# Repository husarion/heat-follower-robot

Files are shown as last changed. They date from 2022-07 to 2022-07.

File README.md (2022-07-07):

# Heat Follower

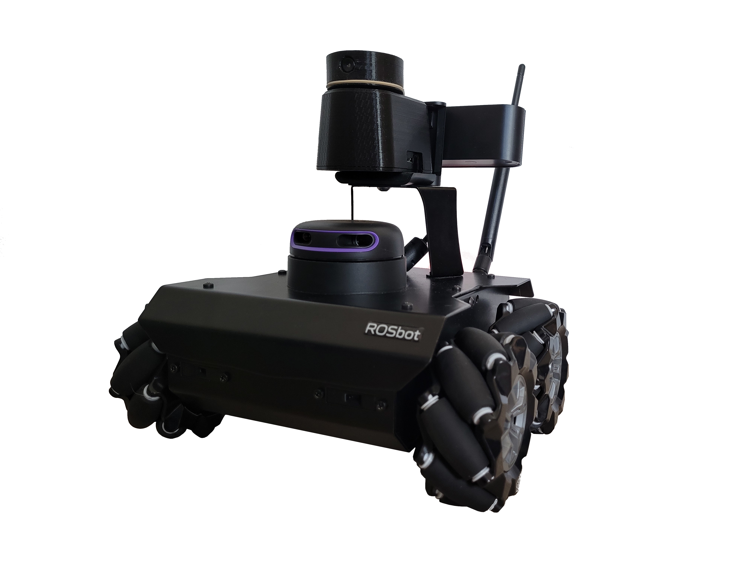
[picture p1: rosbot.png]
3d model


## Description

**Heat Follower** is a project based on the ROSbot Pro platform, that follows heat by using a 360 degree thermal camera. It utilizes a MLX90641 sensor which is a 16x12 pixels IR sensor array. With some custom hardware it is possible to rotate this sensor and get a surround infrared image.

## Hardware

Hardware used in this project:
 - [ROSbot PRO](https://husarion.com/manuals/rosbot/#rosbot-pro)
 - [IR Thermal Sensor Array](https://www.melexis.com/en/product/mlx90641/high-operating-temperature-fir-thermal-sensor-array)
 - [Slip Ring](https://www.sparkfun.com/products/13064)
 - [Custom PCB designed in Eagle](https://github.com/husarion/heat-follower-robot/tree/main/CAD/PCB)
 - [Custom enclosure designed in Fusion 360](https://github.com/husarion/heat-follower-robot/tree/main/CAD)
 
## Software

### Thermal Camera

Software for Thermal Camera is written in [PlatformIO](https://platformio.org/) IDE to ensure compatibility with multiple platforms. MLX90641 [API](https://github.com/melexis/mlx90641-library) is used to ensure proper communication with the IR Sensor. It is slightly modified to support STM32's hardware.
Micro-ROS libraries are mandatory to communicate with ROSbot.

### ROS2 Python Node

A simple Python node was written to process the input thermal image with OpenCV and steer the robot. 
When a heat source is detected, this node sends rotational and linear velocities via `/cmd_vel` topic. 

### ROS Description

 Topic | Node Name | Description 
 --- | --- | ---
 `/thermal_image` | `/thermal_camera` | Raw thermal image represented with grayscale image (temperature = pixel intensity/100). 
 `/tc_image_devel` | `/thermal_subscriber`| Normalized image with target object contours. 
 `/tc_goal_angle` | `/thermal_subscriber`| Arrow marker pointing at the target angle relative to the robot. 
 
Additionally there are 3 parameters

 Parameter | Node Name | Type | Description
 ---  | --- | --- | ---
 `target_min_temp` | `/thermal_subscriber` | int | Minimum temperature of object 
 `target_max_temp` | `/thermal_subscriber` | int | Maximum temperature of object
 `go_to_hottest_piont` | `/thermal_subscriber` | bool | If true, robot follows the hottest object. If false, robot follows object which temperature is within `target_min_temp` and `target_max_temp`.
 
System schematic diagram:

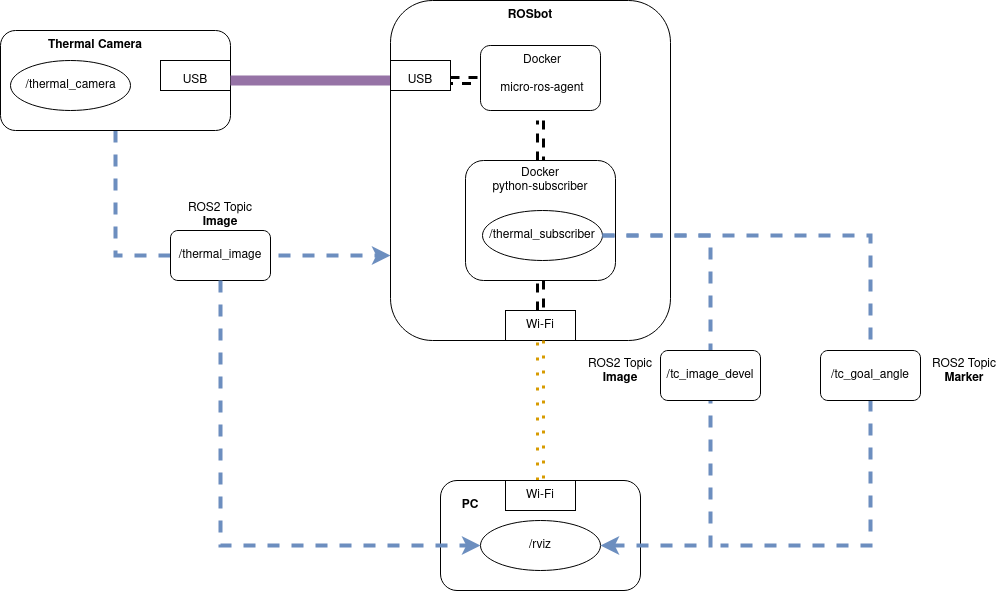
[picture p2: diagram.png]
diagram

 
The camera sends the main topic `/thermal_image` - a raw unprocessed image which is then transformed by `/thermal_subscriber` node. The transformed image published on `/tc_image_devel` containes a normalized image with a contour of an object selected by the algorithm. The angle of a selected object can also be visualized with `/tc_goal_angle` marker that publishes an arrow pointing from **base_link** to the direction of the object.

## Building the project

### Flashing MCU

Open the project with [Visual Studio Code](https://code.visualstudio.com/) with [PlatformIO](https://platformio.org/install/ide?install=vscode) plugin.

**This project is optimized for STM32F4 MCU's - keep that in mind when flashing on your hardware!**

After installing the **PlatformIO** extension to your VSCode, click its icon on the **Activity Bar** then from **Project Tasks** select **General** and **Upload**.

### Running on ROSbot

Clone **robot** folder to your ROSbot, connect the Thermal Camera via USB and run
```bash
cd robot/
docker-compose -f docker-compose.yaml up
```
After downloading all the necessary docker images ROSbot should follow warm objects nearby.

Due to issues connected with micro-ros agent, user must **unplug and plug** the Thermal Camera to reset the connection before running the docker compose. 
### Running Rviz on PC

Clone **pc** folder to your PC and run:

```bash
cd pc/
xhost local:root
docker-compose -f compose.pc.yaml up
```

Rviz should now pop up showing ROSbots surroundings in deep infrared.

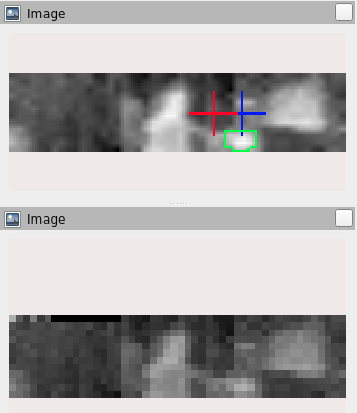
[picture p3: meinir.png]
rviz


If images are not visible click **Add** -> **By topic** -> **/thermal_image**

Here's ROSbot facing a kettle:

rb kettle

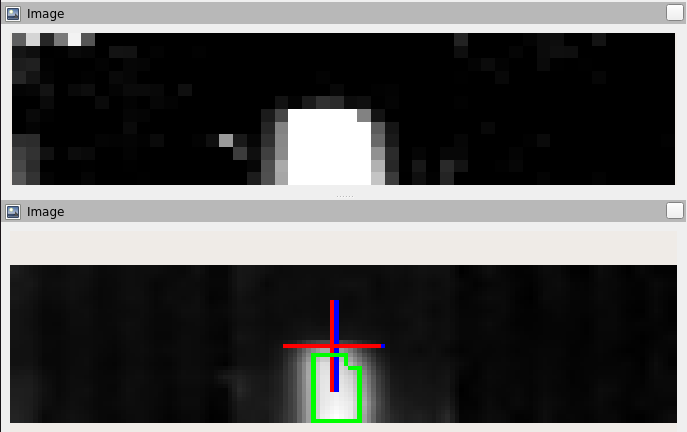
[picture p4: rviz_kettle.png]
rviz kettle


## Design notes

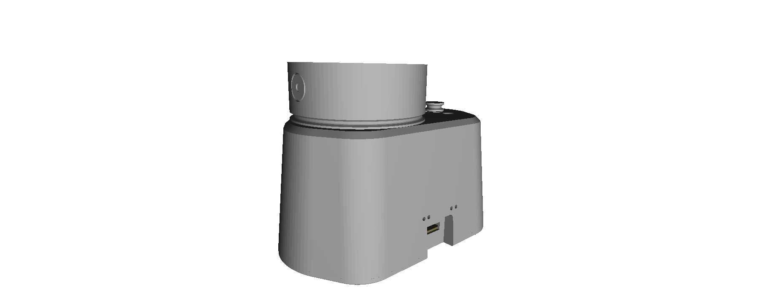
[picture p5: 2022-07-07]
CAD/3dmodel.png

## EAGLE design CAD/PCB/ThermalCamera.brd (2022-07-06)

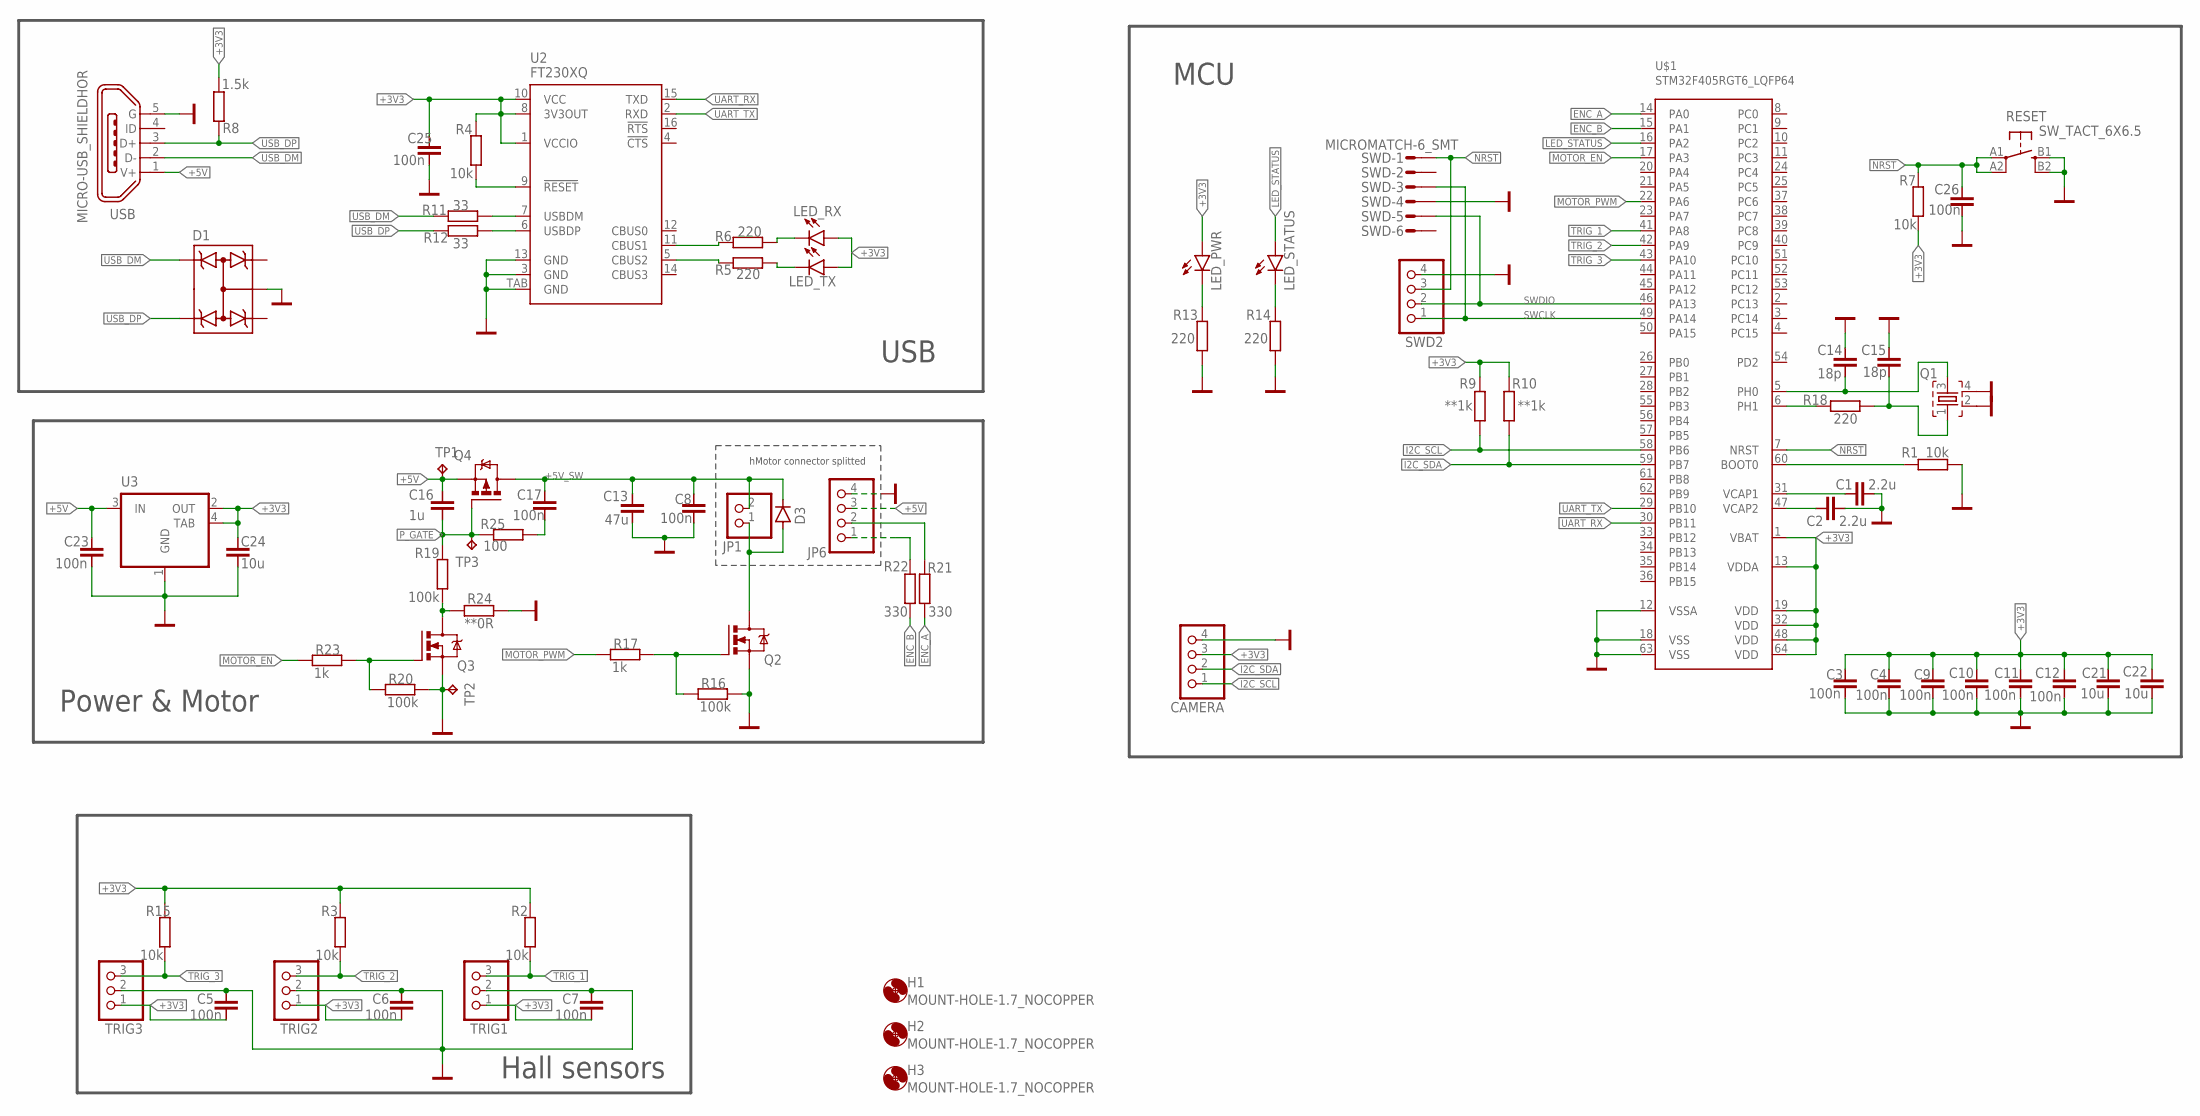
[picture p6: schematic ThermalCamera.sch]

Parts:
C1, C2: 2.2u; 0603
C3, C4, C5, C6, C7, C8, C9, C10, C11, C12, C17, C23, C25, C26: 100n; 0603
C13: 47u; 0805
C14, C15: 18p; 0603
C16: 1u; 0603
C21, C22, C24: 10u; 0603
CAMERA: PINHD-1X4; 1X04
D1: TRANSIL-4; SOT323-5
D3: BAR63-03; SOD323
H1, H2, H3: MOUNT-HOLE-1.7_NOCOPPER; 1.7-NO_COPPER
JP1: PINHD-1X2; 1X02
JP6: PINHD-1X4; 1X04
LED_PWR: LEDCHIPLED_0603; CHIPLED_0603
LED_RX: LEDCHIPLED_0603; CHIPLED_0603
LED_STATUS: LEDCHIPLED_0603; CHIPLED_0603
LED_TX: LEDCHIPLED_0603; CHIPLED_0603
Q1: CRYSTAL_4PIN-5X3.2; CRYSTAL_5X3.2_4PIN
Q2, Q3: NMOS-SOT23; SOT23
Q4: PMOS-SOT23; SOT23
R1, R2, R3, R4, R7, R15: 10k; 0603
R5, R6, R13, R14, R18: 220; 0603
R8: 1.5k; 0603
R9, R10: **1k; 0603
R11, R12: 33; 0603
R16, R19, R20: 100k; 0603
R17, R23: 1k; 0603
R21, R22: 330; 0603
R24: **0R; 0603
R25: 100; 0603
RESET: SW_TACT_6X6.5
SWD: MICROMATCH-6_SMT
SWD2: PINHD-1X4; 1X04
TP1, TP2: TPTP12R; TP12R
TP3: TPTP06R; TP06R
TRIG1, TRIG2, TRIG3: PINHD-1X3; 1X03
U2: FT230XQ; QFN16
U3: REG1117; SOT223
U$1: STM32F405RGT6_LQFP64; SQFP-S-10X10-64
USB: MICRO-USB_SHIELDHOR; MICRO_USB_6_SHIELD

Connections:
+3V3: C3.1, C4.1, C5.2, C6.2, C7.2, C9.1, C10.1, C11.1, C12.1, C21.1, C22.1, C24.1, C25.1, CAMERA.3, LED_PWR.A, LED_RX.A, LED_TX.A, R2.2, R3.2, R4.2, R7.1, R8.1, R9.2, R10.2, R15.2, TRIG1.1, TRIG2.1, TRIG3.1, U2.1 (VCCIO), U2.8 (3V3OUT), U2.10 (VCC), U3.2 (OUT), U3.4 (TAB), U$1.1 (VBAT), U$1.13 (VDDA), U$1.19 (VDD), U$1.32 (VDD), U$1.48 (VDD), U$1.64 (VDD)
+5V: C16.1, C23.1, JP6.3, Q4.2 (S), TP1.TP, U3.3 (IN), USB.1 (V+)
+5V_SW: C8.1, C13.1, C17.1, D3.1 (C), JP1.2, Q4.3 (D)
ENC_A: R21.2, U$1.14 (PA0)
ENC_B: R22.1, U$1.15 (PA1)
GND: C1.2, C2.2, C3.2, C4.2, C5.1, C6.1, C7.1, C8.2, C9.2, C10.2, C11.2, C12.2, C13.2, C14.1, C15.1, C21.2, C22.2, C23.2, C24.2, C25.2, C26.2, CAMERA.4, D1.2, JP6.4, Q1.2, Q1.4, Q2.2 (S), Q3.2 (S), R1.2, R13.2, R14.2, R16.1, R20.1, R24.1, RESET.B1 (S), RESET.B2 (S1), SWD.P$4, SWD2.4, TP2.TP, TRIG1.2, TRIG2.2, TRIG3.2, U2.3 (GND), U2.13 (GND), U2.TAB (GND), U3.1 (GND), U$1.12 (VSSA), U$1.18 (VSS), U$1.63 (VSS), USB.5 (G)
I2C_SCL: CAMERA.1, R9.1, U$1.58 (PB6)
I2C_SDA: CAMERA.2, R10.1, U$1.59 (PB7)
LED_STATUS: LED_STATUS.A, U$1.16 (PA2)
MOTOR_EN: R23.2, U$1.17 (PA3)
MOTOR_PWM: R17.2, U$1.22 (PA6)
unnamed: R1.1, U$1.60 (BOOT0)
unnamed: C1.1, U$1.31 (VCAP1)
unnamed: C2.1, U$1.47 (VCAP2)
unnamed: D3.2 (A), JP1.1, Q2.3 (D)
unnamed: R4.1, U2.9 (!RESET)
unnamed: R6.2, U2.11 (CBUS1)
unnamed: R5.2, U2.5 (CBUS2)
unnamed: LED_RX.C, R6.1
unnamed: LED_TX.C, R5.1
unnamed: Q3.3 (D), R19.1, R24.2
unnamed: R11.1, U2.7 (USBDM)
unnamed: R12.1, U2.6 (USBDP)
unnamed: LED_PWR.C, R13.1
unnamed: LED_STATUS.C, R14.1
unnamed: Q2.1 (G), R16.2, R17.1
unnamed: R18.1, U$1.6 (PH1)
unnamed: C15.2, Q1.1, R18.2
unnamed: JP6.2, R21.1
unnamed: C17.2, R25.1
unnamed: Q3.1 (G), R20.2, R23.1
unnamed: JP6.1, R22.2
NRST: C26.1, R7.2, RESET.A1, RESET.A2 (P1), SWD.P$1, SWD2.3, U$1.7 (NRST)
OSC_IN: C14.2, Q1.3, U$1.5 (PH0)
P_GATE: C16.2, Q4.1 (G), R19.2, R25.2, TP3.TP
SWCLK: SWD.P$3, SWD2.1, U$1.49 (PA14)
SWDIO: SWD.P$5, SWD2.2, U$1.46 (PA13)
TRIG_1: R2.1, TRIG1.3, U$1.41 (PA8)
TRIG_2: R3.1, TRIG2.3, U$1.42 (PA9)
TRIG_3: R15.1, TRIG3.3, U$1.43 (PA10)
UART_RX: U2.15 (TXD), U$1.30 (PB11)
UART_TX: U2.2 (RXD), U$1.29 (PB10)
USB_DM: D1.4, R11.2, USB.2 (D-)
USB_DP: D1.5, R8.2, R12.2, USB.3 (D+)

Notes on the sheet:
MCU
Hall sensors
Power & Motor
USB
hMotor connector splitted

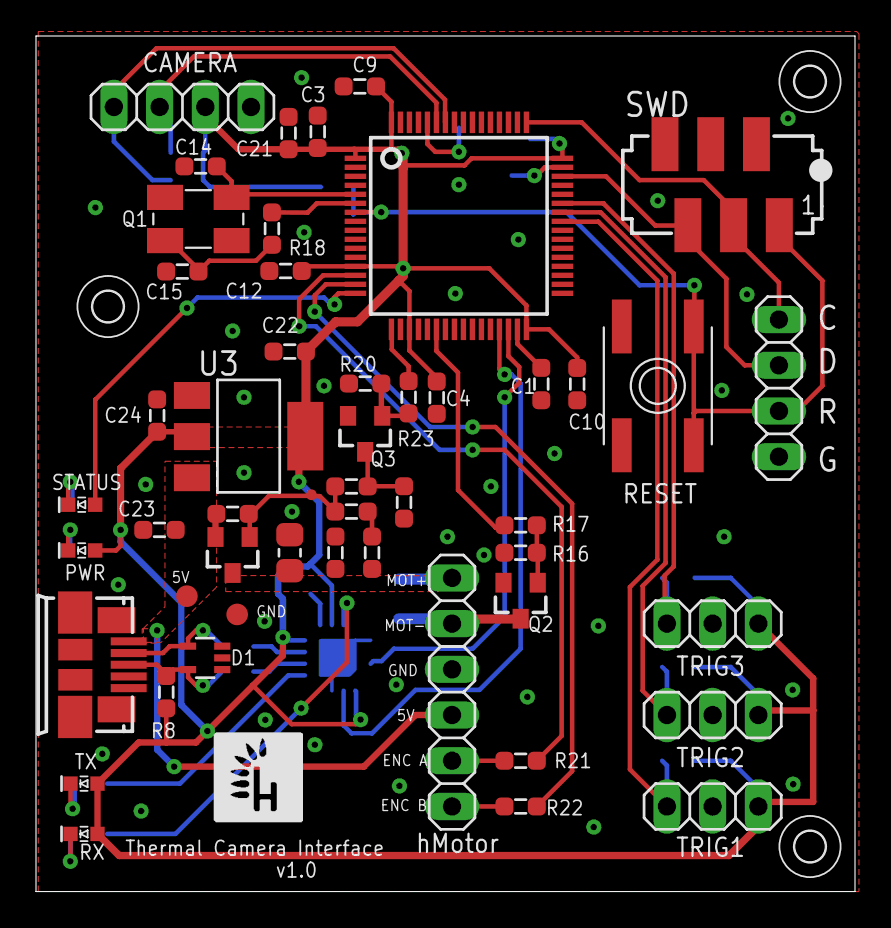
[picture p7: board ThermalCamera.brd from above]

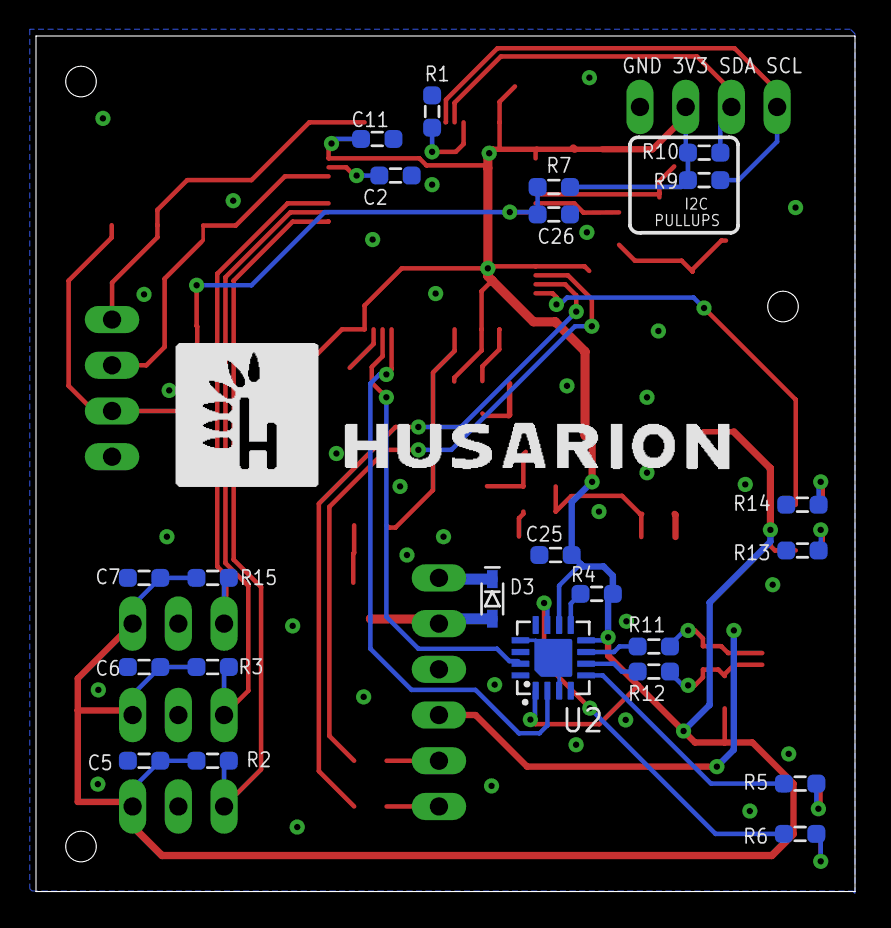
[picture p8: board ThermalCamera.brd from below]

Board: 2 copper layers, 45.5 x 47.5 mm, 79 parts (24 on the bottom side), 44 nets.

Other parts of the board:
U$2: HUSARION_SYGNET_5MM
U$3: HUS_NAPIS_BOK_8MM

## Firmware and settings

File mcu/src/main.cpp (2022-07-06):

#define F_CPU 168000000

#include <Arduino.h>
#include <STM32FreeRTOS.h>
#include <micro_ros_arduino.h>
#include <micro_ros_utilities/string_utilities.h>
#include <rcl/error_handling.h>
#include <rcl/rcl.h>
#include <rclc/executor.h>
#include <rclc/rclc.h>
#include <rclc_parameter/rclc_parameter.h>
#include <std_msgs/msg/string.h>
#include <sensor_msgs/msg/image.h>
#include <std_msgs/msg/u_int8.h>
#include <std_msgs/msg/u_int16_multi_array.h>
#include "MLX90641_API.h"
#include "MLX90641_I2C_Driver.h"
#include "Motor.h"

#define NODE_NAME "Thermal_Camera"
#define LED_PIN PA2
#define MOTOR_PIN PA6
#define IMAGES 3 //number of camera shots per rotation

#define RCCHECK(fn)                \
  {                                \
    rcl_ret_t temp_rc = fn;        \
    if ((temp_rc != RCL_RET_OK)) { \
      error_loop();                \
    }                              \
  }
#define RCSOFTCHECK(fn)            \
  {                                \
    rcl_ret_t temp_rc = fn;        \
    if ((temp_rc != RCL_RET_OK)) { \
    }                              \
  }


rcl_publisher_t publisher, info_publisher;
rcl_subscription_t subscriber;
sensor_msgs__msg__Image msg;
std_msgs__msg__UInt16MultiArray info_msg;
rclc_executor_t executor;
rclc_support_t support;
rcl_allocator_t allocator;
rcl_node_t node;

static void rclc_spin_task(void *p);
static void publisher_task(void *p);
static void motorTask(void* p);
static void TriggerInterrupt(void);
static void uROS_Init();
static void uROS_DeInit();

enum infoDataType {RPM, TARGET, PID_I, PID_D, PID_E, FIN_PULSE_0, FIN_PULSE_1, FIN_PULSE_2, PULSE};
static paramsMLX90641 MLX_Params;
static uint8_t flag = 0;
static uint8_t imageId;
static uint16_t frameBuffer[16*12*IMAGES]; // [pixel0, pixel1, ...]
static uint16_t infoBuffer[10];
static uint16_t MLX_eeprom[832];
static uint16_t frameData[300];
static uint32_t lastPulseTickMS = 0;
static uint32_t currPulseTickMS = 0;
static float image[192];
static float MLX_Vdd = 0.0f;
static float MLX_Emmisivity = 0.0f;
static float MLX_Ambient = 0.0f;
volatile float targetRPM = 120;
volatile float rpm = 0;
volatile int pulses = 0;
int ret_code = 0;

void error_loop() {
  while (1) {
    digitalWrite(LED_PIN, !digitalRead(LED_PIN));
    delay(100);

    if(rmw_uros_ping_agent(100, 1) == RCL_RET_OK)
    {
      uROS_DeInit();
      setup();
    }
  }
}

void uROS_Init()
{
  RCCHECK(rclc_support_init(&support, 0, NULL, &allocator));
  
  // create node
  RCCHECK(rclc_node_init_default(&node, NODE_NAME, "", &support));

  // create publishers
  RCCHECK(rclc_publisher_init_default(&publisher, &node, ROSIDL_GET_MSG_TYPE_SUPPORT(sensor_msgs, msg, Image), "thermal_image"));
  RCCHECK(rclc_publisher_init_default(&info_publisher, &node, ROSIDL_GET_MSG_TYPE_SUPPORT(std_msgs, msg, UInt16MultiArray), "thermal_camera_info"));

  // create executor
  RCCHECK(rclc_executor_init(&executor, &support.context, 1, &allocator));
}

void uROS_DeInit()
{
  rmw_context_t * rmw_context = rcl_context_get_rmw_context(&support.context);
  (void) rmw_uros_set_context_entity_destroy_session_timeout(rmw_context, 0);

  rcl_publisher_fini(&publisher, &node);
  rclc_support_fini(&support);
  rcl_node_fini(&node);
  rclc_executor_fini(&executor);
}

void setup() 
{
  portBASE_TYPE s1, s2, s3;
  
  MLX90641_I2CInit();
  Motor_Init();
  pinMode(LED_PIN, OUTPUT);
  pinMode(PA8, INPUT);
  pinMode(PA9, OUTPUT);
  pinMode(PA10, OUTPUT);
  attachInterrupt(PA8, TriggerInterrupt, FALLING);

  //image message definition 
  msg.header.frame_id.data = "map";
  msg.width = 16*IMAGES;
  msg.height = 12;
  msg.encoding.data = "mono16";
  msg.is_bigendian = false;
  msg.step = 32*IMAGES;
  msg.data.capacity = 12*16*IMAGES;
  msg.data.data = (uint8_t*)frameBuffer; //set frameBuffer as message data field
  msg.data.size = sizeof(frameBuffer);

  info_msg.data.capacity = 10;
  info_msg.data.data = (uint16_t*)infoBuffer;
  info_msg.data.size = 10;

  set_microros_transports(); //open serial communication 
  allocator = rcl_get_default_allocator();
  delay(1000); //wait for sensor to boot up
  
  //set image capture mode
  MLX90641_I2CWrite(0x33, 0x800D, 0x0901);
  delay(1000);
  
  //dump eeprom and check for errors
  ret_code = MLX90641_DumpEE(0x33, MLX_eeprom); 
  if(ret_code != 0)
  {
    while(1)
    {
      switch(ret_code)
      {
        case -1:
          digitalWrite(LED_PIN, !digitalRead(LED_PIN));
          delay(1000);      
        break;
        case -9:
          digitalWrite(LED_PIN, !digitalRead(LED_PIN));
          delay(500);      
        break;
        case -10:
          digitalWrite(LED_PIN, !digitalRead(LED_PIN));
          delay(50);      
        break;
        default:
        digitalWrite(LED_PIN, LOW);
        break;
      }
    }
  }

  digitalWrite(LED_PIN, HIGH); 
  MLX90641_SetResolution(0x33, 0);
  MLX90641_SynchFrame(0x33);

  int error = MLX90641_ExtractParameters(MLX_eeprom, &MLX_Params);
  if(error)
  {
    error_loop;
  }

  MLX90641_SetRefreshRate(0x33, 0x07);
  delay(10);
  MLX90641_SubpagesMode(0x33, 1);
  delay(10);
  
  //initialize variables
  MLX90641_GetFrameData(0x33, frameData);
  MLX_Vdd = MLX90641_GetVdd(frameData, &MLX_Params);
  MLX_Emmisivity = MLX90641_GetEmissivity(&MLX_Params);
  MLX_Ambient = MLX90641_GetTa(frameData, &MLX_Params);
  MLX_Params.alpha[36] = 10000;// broken pixel fix
  MLX90641_CalculateTo(frameData, &MLX_Params, MLX_Emmisivity, MLX_Ambient, image);

  uROS_Init();

  // create publisher task
  s1 = xTaskCreate(
      publisher_task, (const portCHAR *)"publisher_task",
      configMINIMAL_STACK_SIZE + 1000, NULL, tskIDLE_PRIORITY + 2, NULL);

  // create spin task
  s2 = xTaskCreate(rclc_spin_task, "rclc_spin_task",
                   configMINIMAL_STACK_SIZE + 1000, NULL, tskIDLE_PRIORITY + 1,
                   NULL);

  //motor task
  s3 = xTaskCreate(motorTask, "motorTask", configMINIMAL_STACK_SIZE+1000, NULL, tskIDLE_PRIORITY+2, NULL);

  // check for creation errors
  if (s1 != pdPASS || s2 != pdPASS || s3!=pdPASS ) {
    while (1)
      ;
  }
  // start FreeRTOS
  vTaskStartScheduler();
}

static void rclc_spin_task(void *p) 
{
  UNUSED(p);

  TickType_t xLastWakeTime = xTaskGetTickCount();
  while (1) {
    rclc_executor_spin(&executor);
    vTaskDelayUntil(&xLastWakeTime, 1);
  }
}

static void publisher_task(void *p) 
{
  UNUSED(p);

  TickType_t xLastWakeTime = xTaskGetTickCount();
  static uint16_t finishPulse[3];
  while (1) 
  { 
    //take a picture at specific position
    pulses = TIM2->CNT;
      taskENTER_CRITICAL();

    if( pulses == 20) 
    {
        imageId = 1;
    }
    else if(pulses == 110) 
    {
      
       imageId = 0;
    }
    else if(pulses == 245)
    {
        imageId = 2;
    }
    else 
    {
      imageId = 100;
    }
    taskEXIT_CRITICAL();

    // visualisation
    if(imageId<100)
    {
      // MLX90641_TriggerMeasurement(0x33);
      MLX90641_SynchFrame(0x33);
      taskENTER_CRITICAL();
      digitalWrite(PA9, HIGH);  
      vTaskDelay(10);
      MLX90641_GetFrameData(0x33, frameData);
      MLX_Ambient = MLX90641_GetTa(frameData, &MLX_Params);
      MLX90641_CalculateTo(frameData, &MLX_Params, MLX_Emmisivity, MLX_Ambient, image);
      finishPulse[imageId] = TIM2->CNT;
     // MLX90641_BadPixelsCorrection(36, image);
      MLX90641_BadPixelsCorrection(0, image);
      for(uint8_t i = 0; i< 192; i++)
      {
      //convert float to uint16 and mirror the image(from right to left)
      if(image[(int(i/16)*16 + 15) - (i - int(i/16)*16)] <0)
      {
        frameBuffer[int(i/16)*32 + i + (16*imageId)] = 0;
      }
      else
      {
        frameBuffer[int(i/16)*32 + i + (16*imageId)] = (uint16_t)(image[(int(i/16)*16 + 15) - (i - int(i/16)*16) ]*100); //magic
      }
      // frameBuffer[int(i/16)*32 + i + map(TIM2->CNT, 0, 290, 32, 0)] = (uint16_t)(image[(int(i/16)*16 + 15) - (i - int(i/16)*16) ]*100);
      // frameBuffer[i] = (uint16_t)(image[(int(i/16)*16 + 15) - (i - int(i/16)*16) ]*100);
      // frameBuffer[i] = (uint16_t)roundf(image[i]*100);
      }
      // for(uint8_t i = 0; i< 48; i++)
      // {
      //   frameBuffer[int(i/4)*44 + i + map(TIM2->CNT, 0, 290, 44, 0)] = (uint16_t)(image[(int(i/4)*16 + 9) - (i - int(i/4)*4) ]*100);
      // }
      taskEXIT_CRITICAL();
      if(imageId == 0)
      {
        rcl_publish(&publisher, &msg, NULL);
        rcl_publish(&info_publisher, &info_msg, NULL);
      } 
      infoBuffer[FIN_PULSE_0] = finishPulse[0];
      infoBuffer[FIN_PULSE_1] = finishPulse[1];
      infoBuffer[FIN_PULSE_2] = finishPulse[2];
    }
    // vTaskDelayUntil(&xLastWakeTime, 1);
  }
}
static void motorTask(void* p)
{
  UNUSED(p);
  TickType_t xLastWakeTime = xTaskGetTickCount();
  float error = 0.0f;
  float lastError = 1.0f;
  float derivative = 1.0f;
  float integral = 1.0f;
  float kp=0.8f;
  float ki=0.65f;
  float kd=4.0f;
  uint16_t pwm = 0;
  while(1)
  {    
    uint32_t interPulseTime = currPulseTickMS - lastPulseTickMS; // rotation time in milliseconds
    rpm = (float)(1000.0f/interPulseTime)*60.0f;
    if((HAL_GetTick() - currPulseTickMS) > 1500)
    {
      rpm = 0;
    }
    //pid
    error = targetRPM - rpm;
    integral = integral + error;
    derivative = error - lastError;
    pwm = (kp*error) + (ki*integral) + (kd*derivative);

    if(pwm>5000)pwm = 5000;
    if(pwm<0)pwm = 0;

    Motor_Run(pwm);
    lastError = error;

    infoBuffer[RPM] = rpm;
    infoBuffer[TARGET] = targetRPM;
    infoBuffer[PID_E] = error;
    infoBuffer[PID_I] = integral;
    infoBuffer[PID_D] = derivative;
    vTaskDelayUntil(&xLastWakeTime, 175);
  }
}
void loop() {

  digitalWrite(LED_PIN, !digitalRead(LED_PIN));
  delay(1000);
}

static void TriggerInterrupt()
{
  //rotation complete interrupt
  infoBuffer[PULSE] = TIM2->CNT;
  TIM2->CNT = 0;
  
  lastPulseTickMS = currPulseTickMS;
  currPulseTickMS = HAL_GetTick();
}

void TimerInterrupt()
{

}

void SystemClock_Config(void)
{
  RCC_OscInitTypeDef RCC_OscInitStruct = {0};
  RCC_ClkInitTypeDef RCC_ClkInitStruct = {0};

  /** Configure the main internal regulator output voltage
  */
  __HAL_RCC_PWR_CLK_ENABLE();
  __HAL_PWR_VOLTAGESCALING_CONFIG(PWR_REGULATOR_VOLTAGE_SCALE1);

  /** Initializes the RCC Oscillators according to the specified parameters
  * in the RCC_OscInitTypeDef structure.
  */
  RCC_OscInitStruct.OscillatorType = RCC_OSCILLATORTYPE_HSE;
  RCC_OscInitStruct.HSEState = RCC_HSE_ON;
  RCC_OscInitStruct.PLL.PLLState = RCC_PLL_ON;
  RCC_OscInitStruct.PLL.PLLSource = RCC_PLLSOURCE_HSE;
  RCC_OscInitStruct.PLL.PLLM = 4;
  RCC_OscInitStruct.PLL.PLLN = 168;
  RCC_OscInitStruct.PLL.PLLP = RCC_PLLP_DIV2;
  RCC_OscInitStruct.PLL.PLLQ = 4;
  if (HAL_RCC_OscConfig(&RCC_OscInitStruct) != HAL_OK)
  {
    Error_Handler();
  }

  /** Initializes the CPU, AHB and APB buses clocks
  */
  RCC_ClkInitStruct.ClockType = RCC_CLOCKTYPE_HCLK|RCC_CLOCKTYPE_SYSCLK
                              |RCC_CLOCKTYPE_PCLK1|RCC_CLOCKTYPE_PCLK2;
  RCC_ClkInitStruct.SYSCLKSource = RCC_SYSCLKSOURCE_PLLCLK;
  RCC_ClkInitStruct.AHBCLKDivider = RCC_SYSCLK_DIV1;
  RCC_ClkInitStruct.APB1CLKDivider = RCC_HCLK_DIV4;
  RCC_ClkInitStruct.APB2CLKDivider = RCC_HCLK_DIV2;

  if (HAL_RCC_ClockConfig(&RCC_ClkInitStruct, FLASH_LATENCY_5) != HAL_OK)
  {
    Error_Handler();
  }
}

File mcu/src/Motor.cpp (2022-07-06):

#include "Motor.h"
GPIO_InitTypeDef gpio;
TIM_HandleTypeDef htim3, htim2;
TIM_ClockConfigTypeDef sClockSourceConfig = {0};
TIM_MasterConfigTypeDef sMasterConfig = {0};
TIM_OC_InitTypeDef sConfigOC = {0};
static uint8_t pulses;
void InterruptHandler(void);
void Motor_Init()
{
    //init PWM Timer
     __HAL_RCC_TIM3_CLK_ENABLE();

    htim3.Instance = TIM3;
    htim3.Init.Prescaler = 168;
    htim3.Init.CounterMode = TIM_COUNTERMODE_UP;
    htim3.Init.AutoReloadPreload = TIM_AUTORELOAD_PRELOAD_ENABLE;
    htim3.Init.ClockDivision = TIM_CLOCKDIVISION_DIV1;
    htim3.Init.Period = 4999;

    HAL_TIM_Base_Init(&htim3);

    sClockSourceConfig.ClockSource = TIM_CLOCKSOURCE_INTERNAL;
    
    HAL_TIM_ConfigClockSource(&htim3, &sClockSourceConfig);

    sMasterConfig.MasterOutputTrigger = TIM_TRGO_RESET;
    sMasterConfig.MasterSlaveMode = TIM_MASTERSLAVEMODE_DISABLE;

    HAL_TIMEx_MasterConfigSynchronization(&htim3, &sMasterConfig);

    sConfigOC.OCMode = TIM_OCMODE_PWM1;
    sConfigOC.Pulse = 0;
    sConfigOC.OCPolarity = TIM_OCPOLARITY_HIGH;
    sConfigOC.OCFastMode = TIM_OCFAST_DISABLE;

    HAL_TIM_PWM_ConfigChannel(&htim3, &sConfigOC, TIM_CHANNEL_1);

    //init Encoder Timer
    __HAL_RCC_TIM2_CLK_ENABLE();
    TIM_Encoder_InitTypeDef sConfig = {0};
    TIM_MasterConfigTypeDef sMasterConfig = {0};

    htim2.Instance = TIM2;
    htim2.Init.Prescaler = 0;
    htim2.Init.CounterMode = TIM_COUNTERMODE_UP;
    htim2.Init.Period = 1000;
    htim2.Init.ClockDivision = TIM_CLOCKDIVISION_DIV1;
    htim2.Init.AutoReloadPreload = TIM_AUTORELOAD_PRELOAD_DISABLE;
    sConfig.EncoderMode = TIM_ENCODERMODE_TI12;
    sConfig.IC1Polarity = TIM_ICPOLARITY_RISING;
    sConfig.IC1Selection = TIM_ICSELECTION_DIRECTTI;
    sConfig.IC1Prescaler = TIM_ICPSC_DIV1;
    sConfig.IC1Filter = 20;
    sConfig.IC2Polarity = TIM_ICPOLARITY_RISING;
    sConfig.IC2Selection = TIM_ICSELECTION_DIRECTTI;
    sConfig.IC2Prescaler = TIM_ICPSC_DIV1;
    sConfig.IC2Filter = 20;
    HAL_TIM_Encoder_Init(&htim2, &sConfig);
    HAL_NVIC_SetPriority(TIM2_IRQn, 3, 0);
    HAL_NVIC_EnableIRQ(TIM2_IRQn);

    sMasterConfig.MasterOutputTrigger = TIM_TRGO_RESET;
    sMasterConfig.MasterSlaveMode = TIM_MASTERSLAVEMODE_DISABLE;
    HAL_TIMEx_MasterConfigSynchronization(&htim2, &sMasterConfig);
    
    //init GPIO

    __HAL_RCC_GPIOA_CLK_ENABLE();
    gpio.Pin = GPIO_PIN_0|GPIO_PIN_1;
    gpio.Mode = GPIO_MODE_AF_PP;
    gpio.Pull = GPIO_NOPULL;
    gpio.Speed = GPIO_SPEED_FREQ_LOW;
    gpio.Alternate = GPIO_AF1_TIM2;
    HAL_GPIO_Init(GPIOA, &gpio);
    gpio.Pin = GPIO_PIN_6;
    gpio.Mode = GPIO_MODE_AF_PP;
    gpio.Pull = GPIO_NOPULL;
    gpio.Alternate = GPIO_AF2_TIM3;
    gpio.Speed = GPIO_SPEED_FREQ_LOW;
    HAL_GPIO_Init(GPIOA, &gpio);

    HAL_TIM_PWM_Start(&htim3, TIM_CHANNEL_1); 
    __HAL_TIM_SET_COMPARE(&htim3, TIM_CHANNEL_1, 0);

    HAL_TIM_Encoder_Start_IT(&htim2, TIM_CHANNEL_ALL);
}

void Motor_Run(int speed)
{
    __HAL_TIM_SET_COMPARE(&htim3, TIM_CHANNEL_1, speed);
}

int Motor_GetPulses()
{
    return (int) pulses;
}

void InterruptHandler(void)
{
    pulses = TIM2->CNT;
}

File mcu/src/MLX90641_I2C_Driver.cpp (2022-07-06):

/**
 * @copyright (C) 2017 Melexis N.V.
 *
 * Licensed under the Apache License, Version 2.0 (the "License");
 * you may not use this file except in compliance with the License.
 * You may obtain a copy of the License at
 *
 *     http://www.apache.org/licenses/LICENSE-2.0
 *
 * Unless required by applicable law or agreed to in writing, software
 * distributed under the License is distributed on an "AS IS" BASIS,
 * WITHOUT WARRANTIES OR CONDITIONS OF ANY KIND, either express or implied.
 * See the License for the specific language governing permissions and
 * limitations under the License.
 *
 */
#include "MLX90641_I2C_Driver.h"

I2C_HandleTypeDef i2c;
GPIO_InitTypeDef i2c_gpio;
void MLX90641_I2CInit()
{
      HAL_Init();
	__HAL_RCC_GPIOB_CLK_ENABLE();
	__HAL_RCC_I2C1_CLK_ENABLE();

    i2c_gpio.Mode = GPIO_MODE_AF_OD;
    i2c_gpio.Alternate = GPIO_AF4_I2C1;
    i2c_gpio.Pin = GPIO_PIN_6 | GPIO_PIN_7;
    i2c_gpio.Pull = GPIO_NOPULL;
    i2c_gpio.Speed = GPIO_SPEED_FREQ_VERY_HIGH;
    HAL_GPIO_Init(GPIOB, &i2c_gpio);

    i2c.Instance = I2C1;
    i2c.Init.ClockSpeed = 1000000;
    i2c.Init.DutyCycle = I2C_DUTYCYCLE_2;
    i2c.Init.OwnAddress1 = 0xFF;
    i2c.Init.AddressingMode = I2C_ADDRESSINGMODE_7BIT;
    i2c.Init.DualAddressMode = I2C_DUALADDRESS_DISABLE;
    i2c.Init.OwnAddress2 = 0xFF;
    i2c.Init.GeneralCallMode = I2C_GENERALCALL_DISABLE;
    i2c.Init.NoStretchMode = I2C_NOSTRETCH_DISABLE;
    HAL_I2C_Init(&i2c);
}

int MLX90641_I2CGeneralReset(void)
{    
    int ack;
    char cmd[2] = {0,0};
    
    cmd[0] = 0x00;
    cmd[1] = 0x06;    
    HAL_I2C_Master_Transmit(&i2c,cmd[0], (uint8_t*)&cmd[1], 1, HAL_MAX_DELAY);
    return 0;

}

int MLX90641_I2CRead(uint8_t slaveAddr, uint16_t startAddress, uint16_t nMemAddressRead, uint16_t *data)
{
     uint8_t sa;                           
    int ack = 0;                               
    int cnt = 0;
    int i = 0;
    char cmd[2] = {0,0};
    char i2cData[1664] = {0};
    uint16_t *p;
    
    p = data;
    sa = (slaveAddr << 1);
    cmd[0] = startAddress >> 8;
    cmd[1] = startAddress & 0x00FF;
     
    HAL_I2C_Mem_Read(&i2c, sa, startAddress, 2, (uint8_t *)&i2cData, 2*nMemAddressRead, HAL_MAX_DELAY);
          
    for(cnt=0; cnt < nMemAddressRead; cnt++)
    {
        i = cnt << 1;
        *p++ = (uint16_t)i2cData[i]*256 + (uint16_t)i2cData[i+1];
    }
    return 0;
} 

void MLX90641_I2CFreqSet(int freq)
{
    HAL_I2C_DeInit(&i2c);
    i2c.Init.ClockSpeed = freq;
    i2c.Instance = I2C1;
    i2c.Init.DutyCycle = I2C_DUTYCYCLE_2;
    i2c.Init.OwnAddress1 = 0xFF;
    i2c.Init.AddressingMode = I2C_ADDRESSINGMODE_7BIT;
    i2c.Init.DualAddressMode = I2C_DUALADDRESS_DISABLE;
    i2c.Init.OwnAddress2 = 0xFF;
    i2c.Init.GeneralCallMode = I2C_GENERALCALL_DISABLE;
    i2c.Init.NoStretchMode = I2C_NOSTRETCH_DISABLE;
    HAL_I2C_Init(&i2c);
}

int MLX90641_I2CWrite(uint8_t slaveAddr, uint16_t writeAddress, uint16_t data)
{
    uint8_t sa;
    int ack = 0;
    char cmd[4] = {0,0,0,0};
    static uint16_t dataCheck;

    sa = (slaveAddr << 1);
    cmd[0] = writeAddress >> 8;
    cmd[1] = writeAddress & 0x00FF;
    cmd[2] = data >> 8;
    cmd[3] = data & 0x00FF;

     HAL_I2C_Master_Transmit(&i2c,sa, (uint8_t*)&cmd, 4, HAL_MAX_DELAY);
   // HAL_I2C_Mem_Write(&i2c, slaveAddr, writeAddress, 1, (uint8_t*)&data, 1,HAL_MAX_DELAY);
    MLX90641_I2CRead(slaveAddr,writeAddress,1, &dataCheck);
    
    if ( dataCheck != data)
    {
        return -2;
    }    
    return -1;

}
